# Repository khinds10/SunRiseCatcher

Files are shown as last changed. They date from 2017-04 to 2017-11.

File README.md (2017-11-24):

# Daily SunRise Catcher
#### Takes many pictures for you at sunrise, capturing the most colorful.

**Bedside Display**
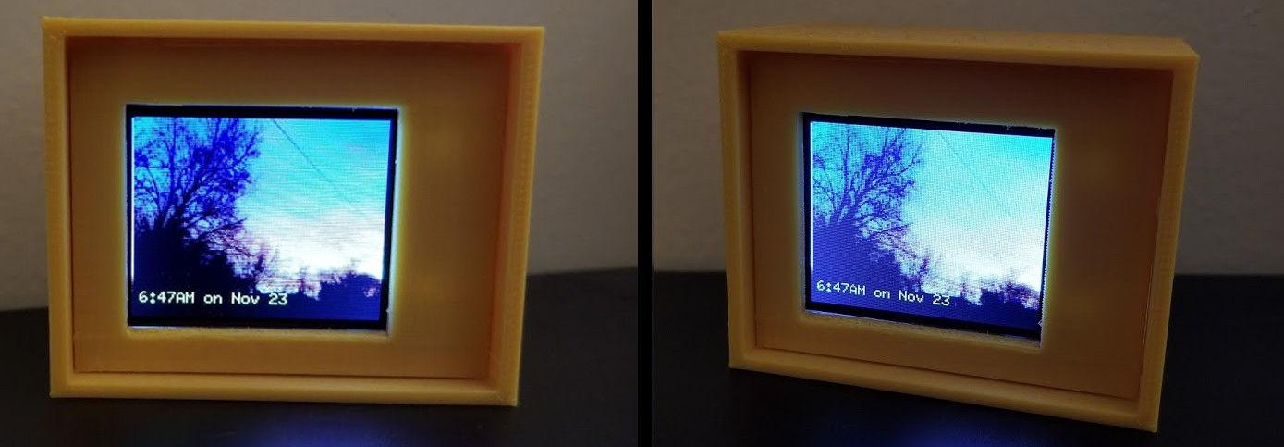
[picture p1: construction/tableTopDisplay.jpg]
Table Top Display


**Morning Email**
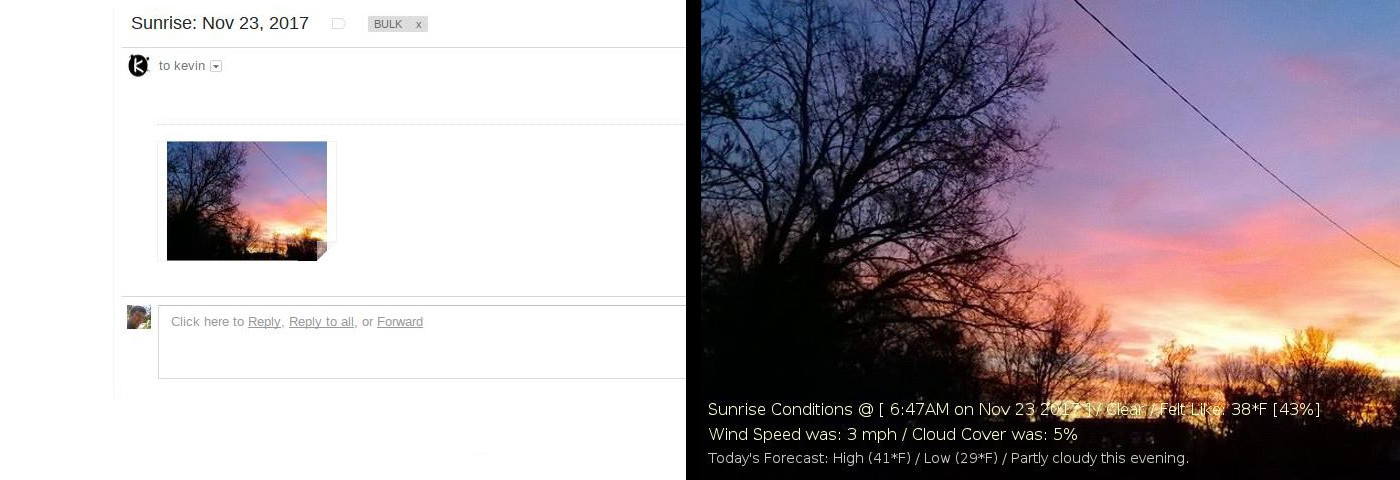
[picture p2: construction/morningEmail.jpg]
Morning Email


#### Flashing RaspberriPi Hard Disk / Install Required Software (Using Ubuntu Linux)

Download "RASPBIAN JESSIE LITE"
https://www.raspberrypi.org/downloads/raspbian/

**Create your new hard disk for DashboardPI**
>Insert the microSD to your computer via USB adapter and create the disk image using the `dd` command
>
> Locate your inserted microSD card via the `df -h` command, unmount it and create the disk image with the disk copy `dd` command
> 
> $ `df -h`
> */dev/sdb1       7.4G   32K  7.4G   1% /media/XXX/1234-5678*
> 
> $ `umount /dev/sdb1`
> 
> **Caution: be sure the command is completely accurate, you can damage other disks with this command**
> 
> *if=location of RASPBIAN JESSIE LITE image file*
> *of=location of your microSD card*
> 
> $ `sudo dd bs=4M if=/path/to/raspbian-jessie-lite.img of=/dev/sdb`
> *(note: in this case, it's /dev/sdb, /dev/sdb1 was an existing factory partition on the microSD)*

**Setting up your RaspberriPi**

*Insert your new microSD card to the raspberrypi and power it on with a monitor connected to the HDMI port*

Login
> user: **pi**
> pass: **raspberry**

Change your account password for security
>`sudo passwd pi`

Enable RaspberriPi Advanced Options
>`sudo raspi-config`

Choose:
`1 Expand File System`

`6 Enable Camera`

`9 Advanced Options`
>`A2 Hostname`
>*change it to "SunRise"*
>
>`A4 SSH`
>*Enable SSH Server*
>
>`A7 I2C`
>*Enable i2c interface*

**Enable the English/US Keyboard**

>`sudo nano /etc/default/keyboard`

> Change the following line:
>`XKBLAYOUT="us"`

**Reboot PI for Keyboard layout changes / file system resizing to take effect**
>$ `sudo shutdown -r now`

**Auto-Connect to your WiFi**

>`sudo nano /etc/wpa_supplicant/wpa_supplicant.conf`

Add the following lines to have your raspberrypi automatically connect to your home WiFi
*(if your wireless network is named "linksys" for example, in the following example)*

	network={
	   ssid="linksys"
	   psk="WIRELESS PASSWORD HERE"
	}

**Reboot PI to connect to WiFi network**

>$ `sudo shutdown -r now`
>
>Now that your PI is finally on the local network, you can login remotely to it via SSH.
>But first you need to get the IP address it currently has.
>
>$ `ifconfig`
>*Look for "inet addr: 192.168.XXX.XXX" in the following command's output for your PI's IP Address*

**Go to another machine and login to your raspberrypi via ssh**

> $ `ssh pi@192.168.XXX.XXX`

**Start Installing required packages**

>$ `sudo apt-get update`
>
>$ `sudo apt-get upgrade`
>
>$ `sudo apt-get install vim git python-smbus i2c-tools python-imaging python-smbus build-essential python-dev rpi.gpio python3 python3-pip libi2c-dev python-picamera python-opencv`

**Update local timezone settings**

>$ `sudo dpkg-reconfigure tzdata`

> select your timezone using the interface

**Setup the simple directory `l` command [optional]**

>$ `vi ~/.bashrc`
>
>*add the following line:*
>
>$ `alias l='ls -lh'`
>
>$ `source ~/.bashrc`

**Fix VIM default syntax highlighting [optional]**

>$ `sudo vi /etc/vim/vimrc`
>
>uncomment the following line:
>
>_syntax on_

**Clone SunRise repository**

`$ cd ~`

`$ https://github.com/khinds10/SunRiseCatcher.git`

**Install the SSMTP mail program to gmail your sunrise pictures**

>$ `sudo apt-get update && apt-get install ssmtp`

>$ `sudo apt-get install sharutils`

**Edit the SSMTP config**

>$ `sudo vi /etc/ssmtp/ssmtp.conf`

>comment out: `mailhub=mail`
>comment out: `FromLineOverride=YES`

>Add the following lines to the end of the file
>
>`AuthUser=your-gmail-address@gmail.com`
>`AuthPass=YOUR GMAIL PASSWORD`
>`FromLineOverride=YES`
>`mailhub=smtp.gmail.com:587`
>`UseSTARTTLS=YES`

**Test emailing to yourself using the installed command**
>$ `echo "This is a test" | mail -s "Test" your-gmail-address@gmail.com`

## Supplies Needed

**Digole 1.8" Serial:UART/I2C/SPI True Color TFT LCD 160x128 Display Module for Arduino/PIC/AVR/PI**
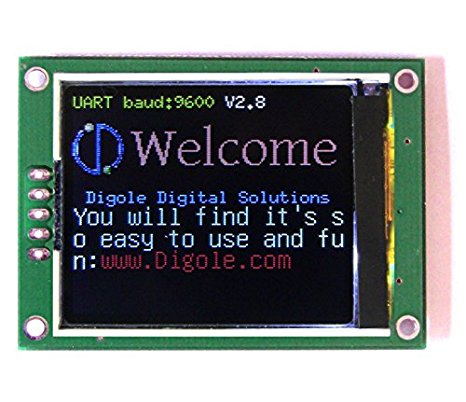
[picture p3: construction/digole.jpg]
Digole Display


**RaspberriPi Zero (W Model w/ built in wireless)**
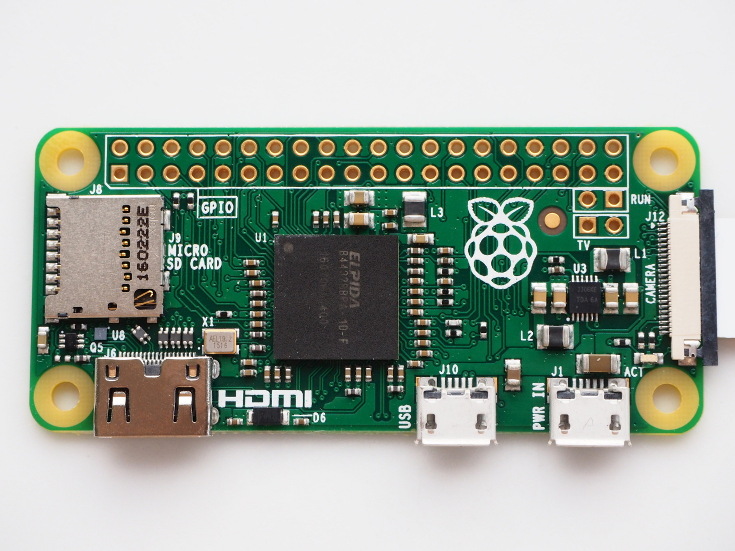
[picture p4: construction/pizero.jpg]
PiZero W


## Build and wire the device

**Prepare the Digole Display for i2C**

On the back of the Digole Display, solder the jumper to assign the display to use the i2c protocol 

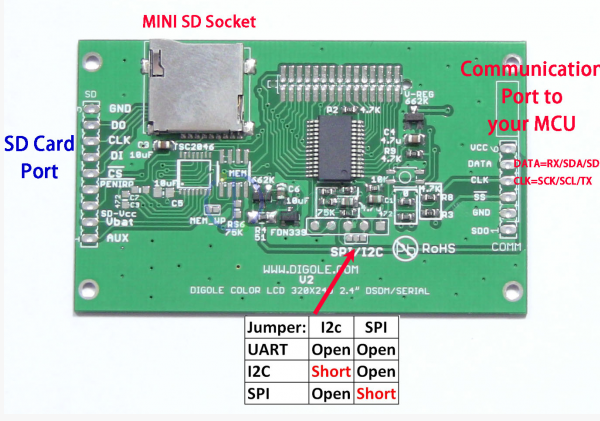
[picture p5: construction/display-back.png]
Digole Display Back


**Digole Display**

Connect the display to the RPi as follows using the below diagram

> GND -> GND
>
> DATA -> SDA
>
> CLK -> SCL
>
> VCC -> 3V

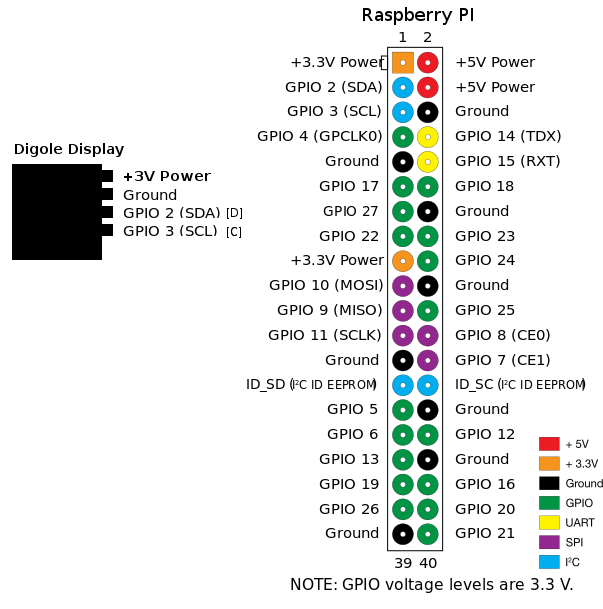
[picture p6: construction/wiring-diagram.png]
Digole Wiring Digole Wiring


## Print the Project Enclosure

Using a 3D printer print the enclosure files included in the 'enclosure/' folder. .x3g files are MakerBot compatible. You can also use the .stl and .blend (Blender Program) files to edit and create your own improvements to the design.

## Assembly

Put the camera and the pizero in the case, attach the front panel to cover any marks from the printing process

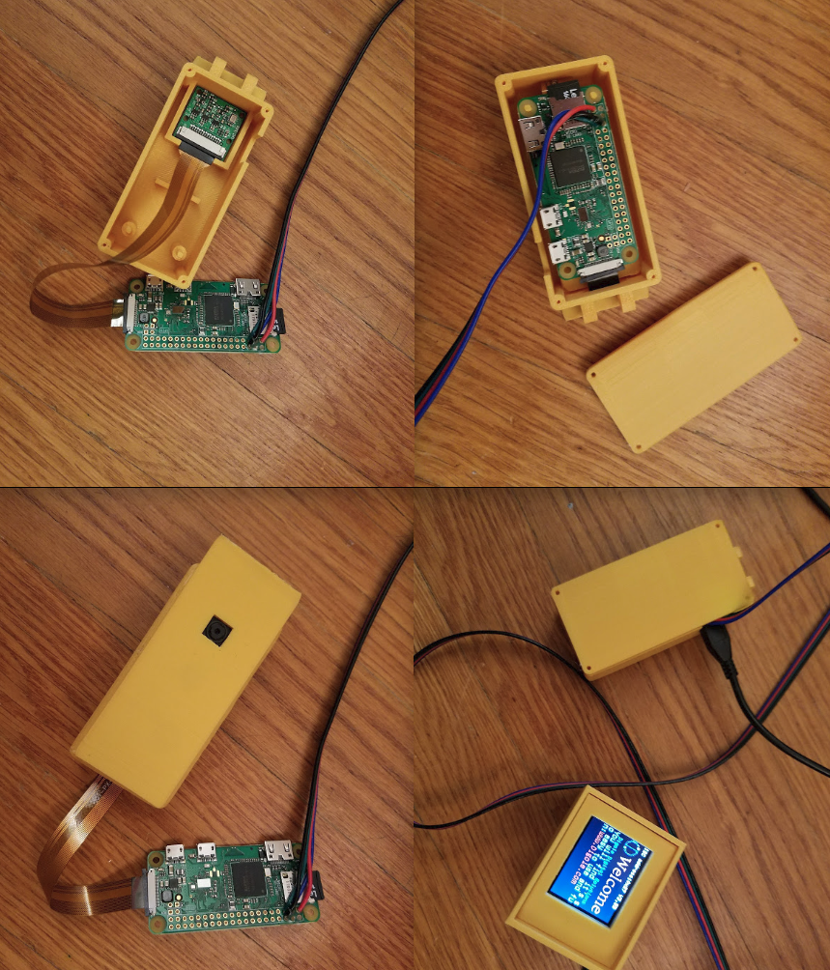
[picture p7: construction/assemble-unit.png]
Assemble Unit


Glue the display to the front panel of the display box and put the wiring through the back hole

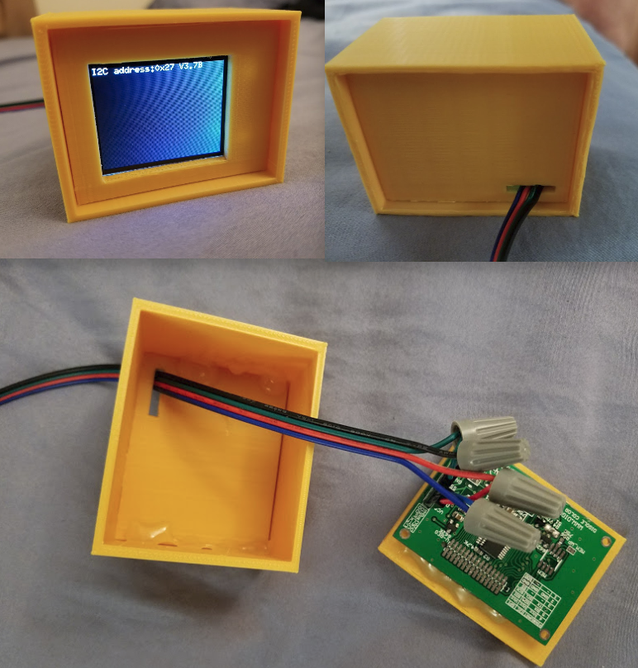
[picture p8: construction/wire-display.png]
Mount Display


Mount the display in an eastern facing window

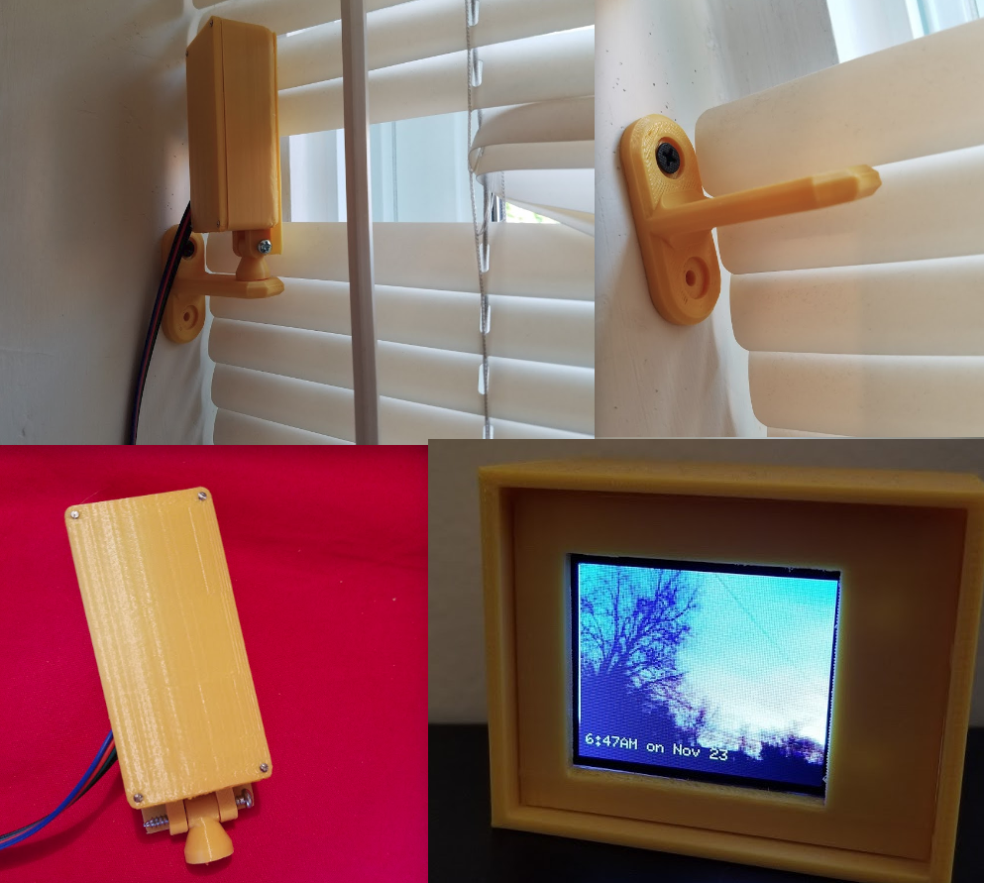
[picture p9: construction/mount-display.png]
Mount Display


**Change your settings.py to match your personal preferences**

`settings.py`

> emailAddress = 'your-email@gmail.com'
>
> weatherAPIURL = 'https://api.forecast.io/forecast/'
> weatherAPIKey = 'YOUR FORECAST.IO KEY HERE'
>
> numberOfSunriseCaptures = 15
> timeToCaptureMinutes = 30

> latitude = 42.4152778
> longitude = -71.1569444

**Run Daily at 4am (via crontab)**

Add the following line to your PI crontab to run the capture program starting at 4am

>$ `crontab -e`
>`0  4  *  *  *  python /home/pi/SunRiseCatcher/capture.py > /home/pi/SunRiseCatcher/capture.out`

### FINISHED!

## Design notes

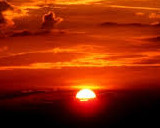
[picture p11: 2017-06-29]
display/image.jpg

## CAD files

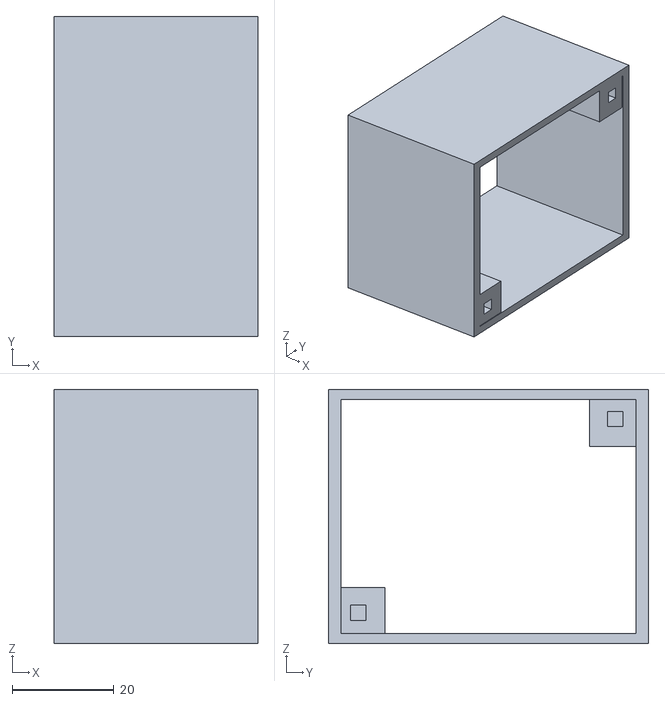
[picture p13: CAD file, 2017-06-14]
enclosure/DisplayBox-Main.stl
40.0 x 62.9 x 49.9

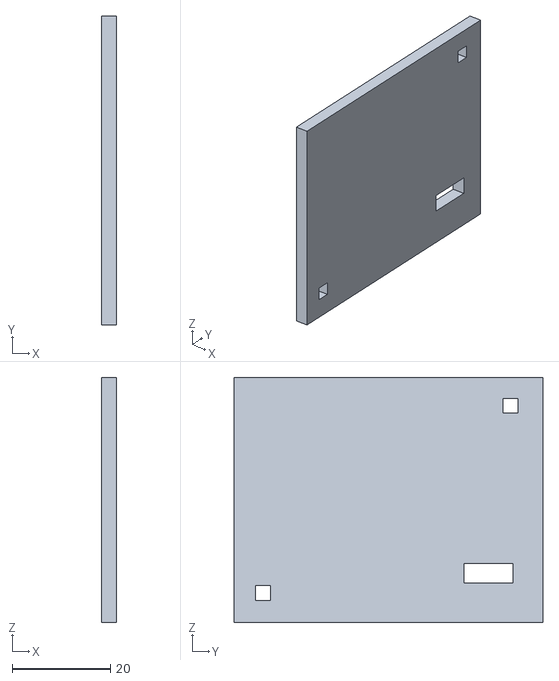
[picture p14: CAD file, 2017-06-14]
enclosure/DisplayBox-Back.stl
3.00 x 62.9 x 49.9

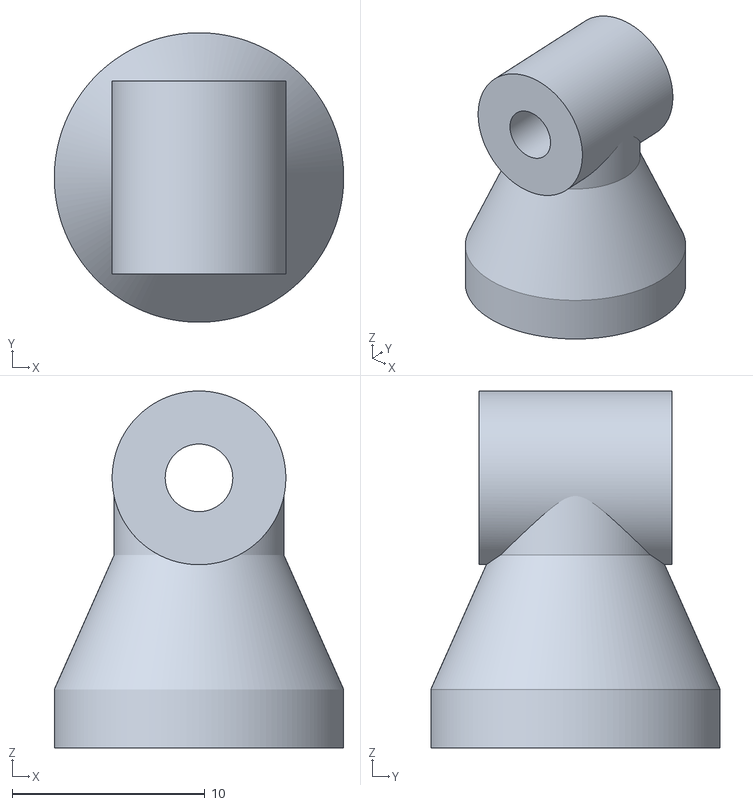
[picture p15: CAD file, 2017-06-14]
enclosure/PigeonSwivel.stl
15.0 x 15.0 x 18.5

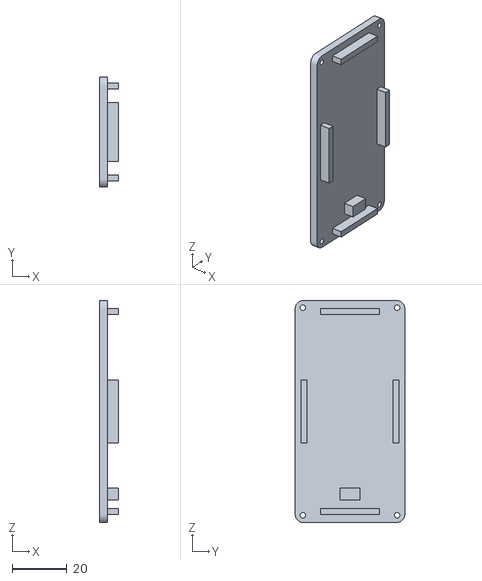
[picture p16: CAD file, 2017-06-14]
enclosure/PigeonLid.stl
7.00 x 40.0 x 81.0

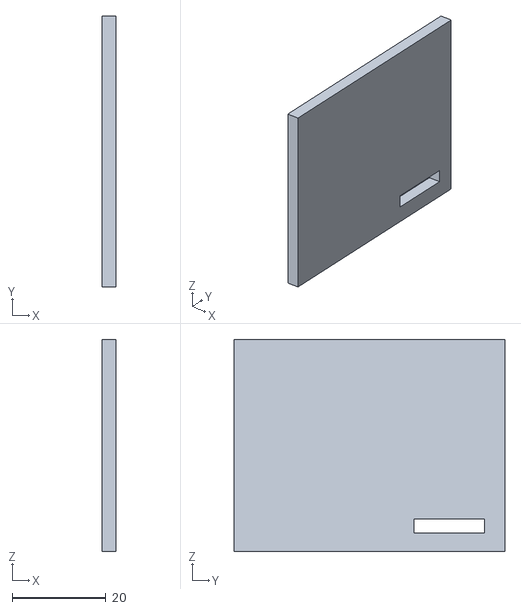
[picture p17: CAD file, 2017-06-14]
enclosure/DisplayBack.stl
3.00 x 57.7 x 45.2

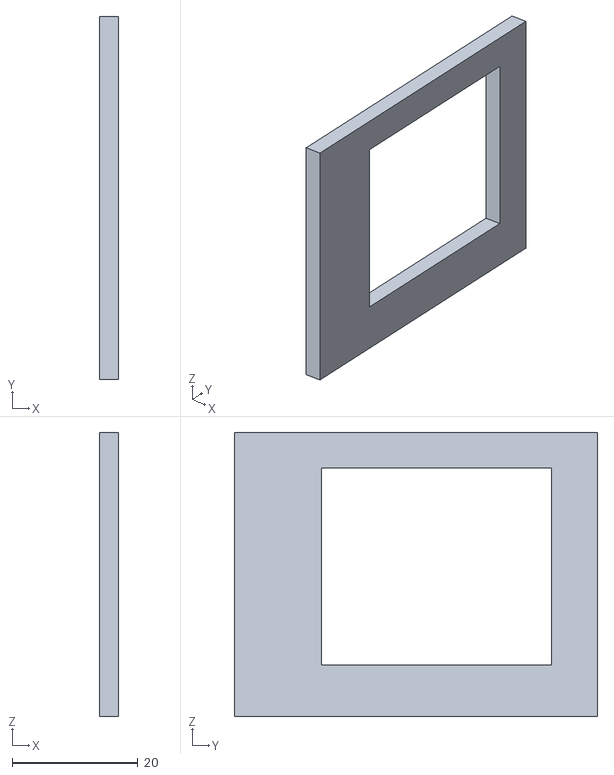
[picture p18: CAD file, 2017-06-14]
enclosure/DisplayBox-Front.stl
3.00 x 57.7 x 45.2

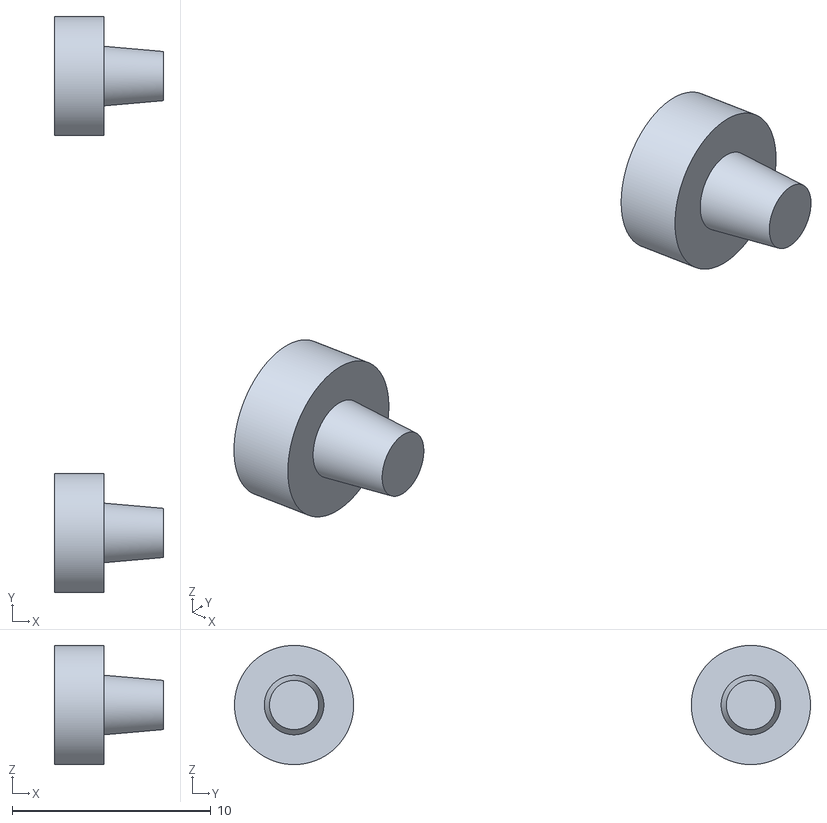
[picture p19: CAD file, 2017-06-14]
enclosure/PigeonBoardPins.stl
5.50 x 29.0 x 6.00

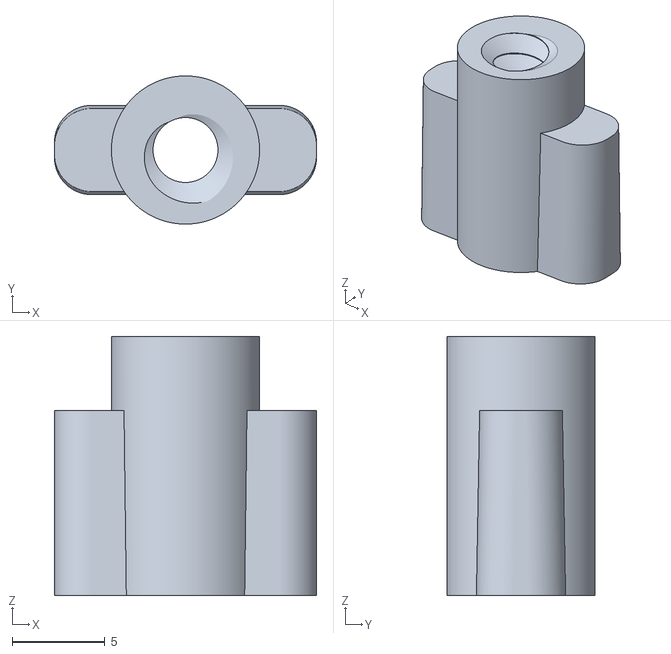
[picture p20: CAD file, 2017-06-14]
enclosure/PigeonWingnut.stl
14.1 x 8.00 x 14.0

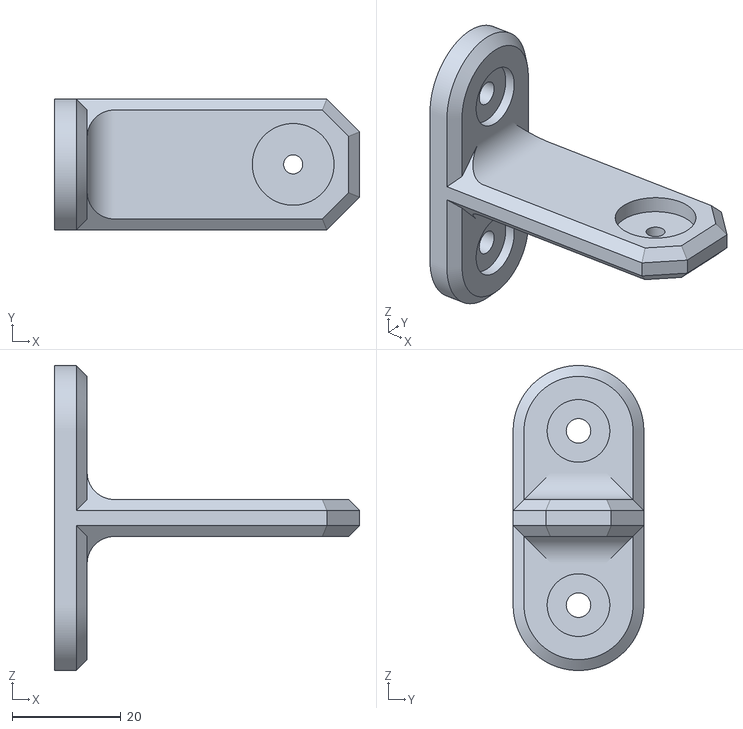
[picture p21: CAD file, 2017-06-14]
enclosure/PigeonMount.stl
56.0 x 24.0 x 56.0

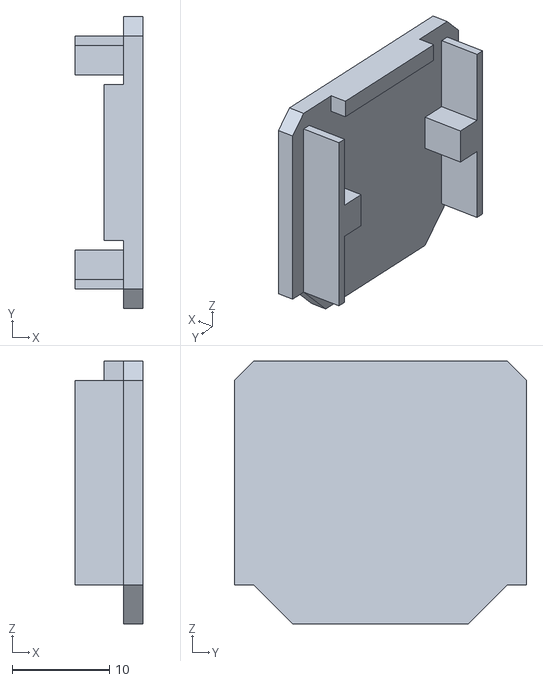
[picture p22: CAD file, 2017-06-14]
enclosure/PigeonHousingCover.stl
7.00 x 30.0 x 27.0

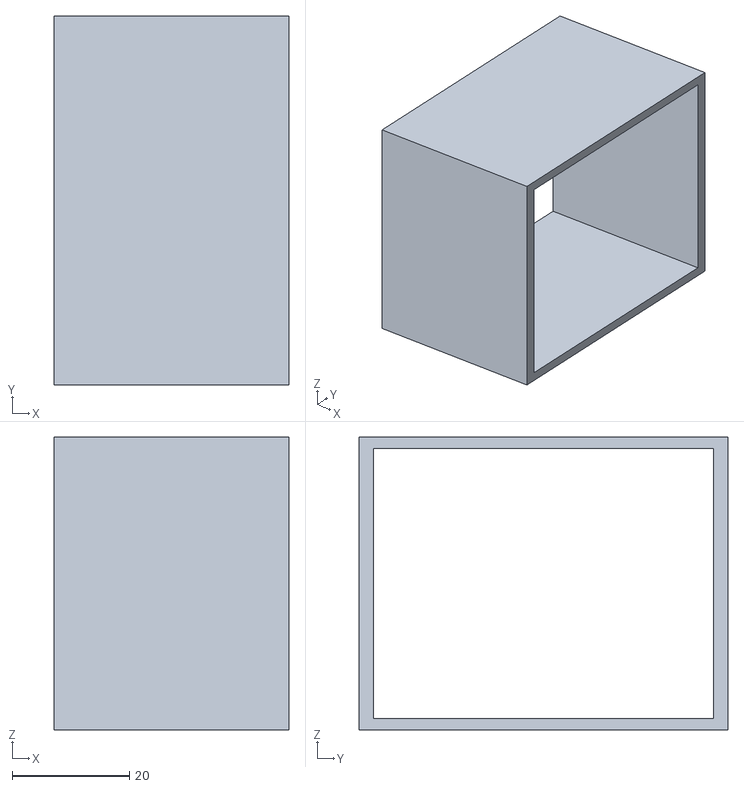
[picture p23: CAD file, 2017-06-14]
enclosure/DisplayBox.stl
40.0 x 62.9 x 49.9

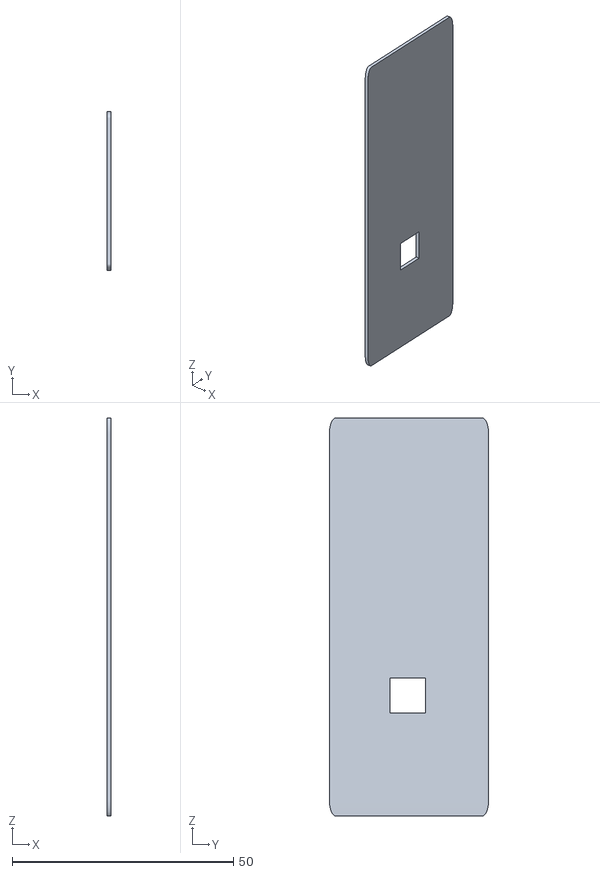
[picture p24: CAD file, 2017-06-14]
enclosure/PigeonFrontCover.stl
1.00 x 36.0 x 90.0

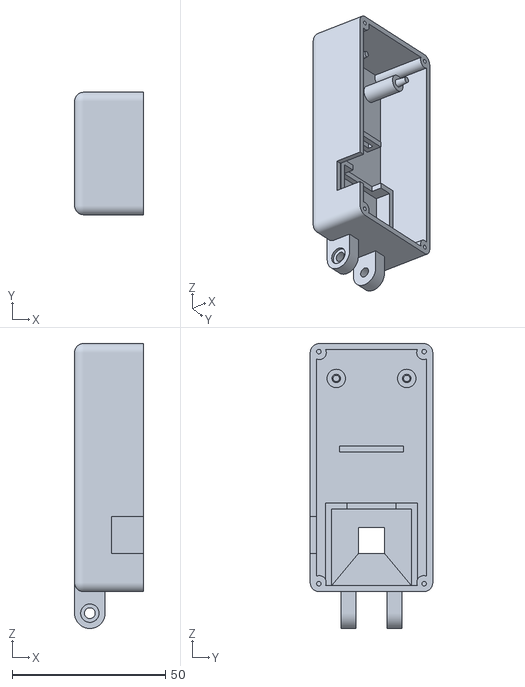
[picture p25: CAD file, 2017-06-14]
enclosure/PigeonHousing.stl
22.5 x 40.0 x 93.0

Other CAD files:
enclosure/SunRiseCatcher.blend
enclosure/SunRiseHousing.blend

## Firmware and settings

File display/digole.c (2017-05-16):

/////////////////////////////////
// Digole Digital
/////////////////////////////////
#include <arpa/inet.h>
#include <dirent.h>
#include <errno.h>
#include <net/if.h>
#include <netinet/in.h>
#include <netinet/in.h>
#include <pthread.h>
#include <stdint.h>
#include <stdio.h>
#include <stdlib.h>
#include <string.h>
#include <stropts.h>
#include <sys/ioctl.h>
#include <sys/socket.h>
#include <sys/types.h>
#include <sys/time.h>
#include <time.h>
#include <unistd.h>
#include <inttypes.h>
#include <linux/i2c-dev.h>
#include <fcntl.h>
#include <sys/ioctl.h>
#include <sys/stat.h>
#include "imageData.h"

#define _TEXT_ 0
#define _GRAPH_ 1
#define _rs 0
#define _rst 2
#define LCDWIDTH 128
#define LCDHEIGHT 64

// an abs() :)
#define abs(a) (((a) < 0) ? -(a) : (a))

// bit set
#define _BV(bit) (0x1 << (bit))
#define swap(a, b) { uint8_t t = a; a = b; b = t; }

int fd,fd2;
const unsigned char fonts[] = {6, 10, 18, 51, 120, 123};

// name of the port we will be using, Rasberry Pi model B (i2c-1)
char *fileName = "/dev/i2c-1";

// address of I2C device Digole
int  address = 0x27;

void delay (unsigned int howLong){
  struct timespec sleeper, dummy ;
  sleeper.tv_sec  = (time_t)(howLong / 1000) ;
  sleeper.tv_nsec = (long)(howLong % 1000) * 1000000 ;
  nanosleep (&sleeper, &dummy) ;
}
 int writebyte (uint8_t command) {
	    if( i2c_smbus_write_byte( fd, command ) < 0 ) {
            printf("\nError writing to i2c slave ");
			return -1;
        }
		return 0;
 }
 int writecmd(char *command) {
		char tmp[1000];
		int i;
		sprintf(tmp,"%s",command);
        printf("\nDigole CMD: %s ",command);
		for (i=0;i<strlen(tmp);i++) {
			printf("\nCharacter is: %c",tmp[i]);
		    if ((writebyte(tmp[i]))==-1) {
				printf("\nError writing to i2c slave ");
				return -1;
			}
		}
		return 0;
 }
void setRot90(void) {
    writecmd("SD1");
}
void setRot180(void) {
    writecmd("SD2");
}
void setRot270(void) {
    writecmd("SD3");
}
void undoRotation(void) {
    writecmd("SD0");
}
void setRotation(uint8_t d) {
    writecmd("SD");
    writebyte(d);
}
void setContrast(uint8_t c) {
    writecmd("CT");
    writebyte(c);
}
int print(char *command) {
    char tmp[1000];
    writecmd("TT");
    writecmd(command);
    writebyte(0);
    return 0;
}
void displayStartScreen(uint8_t c) {
    writecmd("DSS");
    writebyte(c);
}
void drawBox(uint8_t x, uint8_t y, uint8_t w, uint8_t h) {
    writecmd("FR");
    writebyte(x);
    writebyte(y);
    writebyte(x + w);
    writebyte(y + h);
}
void drawFrame(uint8_t x, uint8_t y, uint8_t w, uint8_t h) {
    writecmd("DR");
    writebyte(x);
    writebyte(y);
    writebyte(x + w);
    writebyte(y + h);
}

void setRBGColor(uint8_t r, uint8_t g, uint8_t b){
    writecmd("ESC");
    writebyte(r);
    writebyte(g);
    writebyte(b);
}

void setColor(uint8_t color) {
    writecmd("SC");
    writebyte(color);
}
void drawBoxfill(uint8_t x, uint8_t y, uint8_t w, uint8_t h) {
	drawBox(x, y, w,h);
	drawFrame(x, y, w,h);
}
void clearobd() {
	setColor(0);
	drawBox(0, 0, 128,57);
	setColor(1);
}
void drawCircle(uint8_t x, uint8_t y, uint8_t r, uint8_t f) {
    writecmd("CC");
    writebyte(x);
    writebyte(y);
    writebyte(r);
    writebyte(f);
}
void drawDisc(uint8_t x, uint8_t y, uint8_t r) {
    drawCircle(x, y, r, 1);
}
void drawPixel(uint8_t x, uint8_t y, uint8_t color) {
    writecmd("DP");
    writebyte(x);
    writebyte(y);
    writebyte(color);
}
void drawLine(uint8_t x, uint8_t y, uint8_t x1, uint8_t y1) {
    writecmd("LN");
    writebyte(x);
    writebyte(y);
    writebyte(x1);
    writebyte(y1);
}
void drawLineTo(uint8_t x, uint8_t y) {
    writecmd("LT");
    writebyte(x);
    writebyte(y);
}
void drawHLine(uint8_t x, uint8_t y, uint8_t w) {
    drawLine(x, y, x + w, y);
}
void drawVLine(uint8_t x, uint8_t y, uint8_t h) {
    drawLine(x, y, x, y + h);
}
void nextTextLine(void) {
    writebyte((uint8_t) 0);
    writecmd("TRT");
}
void setFont(uint8_t font) {
    writecmd("SF");
    writebyte(font);
}
void directCommand(uint8_t d) {
    writecmd("MCD");
    writebyte(d);
}
void directData(uint8_t d) {
    writecmd("MDT");
    writebyte(d);
}
void moveArea(uint8_t x0, uint8_t y0, uint8_t x1, uint8_t y1, char xoffset, char yoffset) {
    writecmd("MA");
    writebyte(x0);
    writebyte(y0);
    writebyte(x1);
    writebyte(y1);
    writebyte(xoffset);
    writebyte(yoffset);
}
void uploadStartScreen(int lon,  uint8_t *data,int xdelay) {
     int j,y;
     uint8_t c;
    writecmd("SSS");
    writebyte((uint8_t) (lon % 256));
    writebyte((uint8_t) (lon / 256));
    for (j = 0; j < lon;j++) {
        delay(xdelay);
        c=*(data+j);
        writebyte(c);
		printf(" 0x%.2X ",c);
		if ((j%16)==0) printf(" ");
    }
}
void uploadUserFont(int lon, uint8_t *data, uint8_t sect) {
     uint8_t c;
	 int j;
    writecmd("SUF");
    writebyte(sect);
    writebyte((uint8_t) (lon % 256));
    writebyte((uint8_t) (lon / 256));
    for ( j = 0; j < lon; j++) {
        if((j%32)==0) delay(10);
        delay(2);
        c=*(data+j);
        writebyte(c);
    }
}
void clearScreen(void) {
        writebyte('C');
		writebyte('L');
		writebyte(0);
		writebyte('C');
		writebyte('L');
		writebyte(0);
}
//set display mode
void setMode(uint8_t m) {
        writecmd("DM");
        writebyte(m);
}
//set text position back to previous, only one back allowed
void setTextPosBack(void) {
	writecmd("ETB");
}
void setTextPosOffset(char xoffset, char yoffset) {
	writecmd("ETO");
	writebyte(xoffset);
	writebyte(yoffset);
}
void setTextPosAbs(uint8_t x, uint8_t y) {
	writecmd("ETP");
	writebyte(x);
	writebyte(y);
}
void setLinePattern(uint8_t pattern) {
	writecmd("SLP");
	writebyte(pattern);
 }
void setPrintPos(uint8_t x, uint8_t y, uint8_t graph ) {
        if (graph == _TEXT_)
            writecmd("TP");
		else
            writecmd("GP");
         writebyte(x);
         writebyte(y);
}
void disableCursor(void) {
    writecmd("CS0");
}
void enableCursor(void) {
    writecmd("CS1");
}
void drawStr(uint8_t x, uint8_t y, char *s) {
		setTextPosOffset(x,y);
		print(s);
}
/*----------Functions for Graphic LCD/OLED adapters only---------*/
void drawBitmap(uint8_t x, uint8_t y, uint8_t w, uint8_t h, const uint8_t *bitmap) {
    uint8_t i = 0;
	int j;
    if ((w & 7) != 0)
        i = 1;
    writecmd("DIM");
    writebyte(x); //x;
    writebyte(y);
    writebyte(w);
    writebyte(h);
    for ( j = 0; j < h * ((w >> 3) + i); j++) {
        writebyte(*(bitmap + j));
    }
}

// write 3 colors bytes for pixel image to the display
void drawBitmap256K(uint8_t x, uint8_t y, uint8_t w, uint8_t h, const uint8_t *bitmap,uint8_t c ) {
	int j;
    writecmd("EDIM3");
    writebyte(x);
    writebyte(y);
    writebyte(w);
    writebyte(h);
    for ( j = 0; j < (h * w * 3); j++) {
        writebyte(*(bitmap + j));
    }
}

void drawBitmap256(uint8_t x, uint8_t y, uint8_t w, uint8_t h, const uint8_t *bitmap,uint8_t c ) {
	int j;
    writecmd("EDIM1");
    writebyte(x);
    writebyte(y);
    writebyte(w);
    writebyte(h);
    for ( j = 0; j < h * w; j++) {
        writebyte(*(bitmap + j));
    }
}
void drawBitmapc(uint8_t x, uint8_t y, uint8_t w, uint8_t h, const uint8_t *bitmap,uint8_t c ) {
    uint8_t i = 0;
	int j;
	if (c!=0) c=0xff;
    if ((w & 7) != 0)
        i = 1;
    writecmd("DIM");
    writebyte(x);
    writebyte(y);
    writebyte(w);
    writebyte(h);
    for ( j = 0; j < h * ((w >> 3) + i); j++) {
        writebyte((*(bitmap + j))^c);
    }
}
const char *byte_to_binary(int x) {
    static char b[9];
    b[0] = '\0';
    int z;
    for (z = 128; z > 0; z >>= 1){
        strcat(b, ((x & z) == z) ? "1" : "0");
    }
    return b;
}
 int printxy(uint8_t x, uint8_t y, char *command) {
	setPrintPos(x, y,_TEXT_);
	writecmd("TT");
	writecmd(command);
	writebyte(0);
	return 0;
 }
 int printxy_abs(uint8_t x, uint8_t y, char *command) {
	setTextPosAbs(x, y);
	writecmd("TT");
	writecmd(command);
	writebyte(0);
	return 0;
 }
 int printxyf_abs(uint8_t x, uint8_t y,uint8_t font, char *command) {
	setFont(fonts[font]);
	setTextPosAbs(x, y);
	writecmd("TT");
	writecmd(command);
	writebyte(0);
	return 0;
 }
int printxyf(uint8_t x, uint8_t y,uint8_t font, char *command) {
	setFont(fonts[font]);
	setPrintPos(x, y,_TEXT_);
	writecmd("TT");
	writecmd(command);
	writebyte(0);
	return 0;
 }
int printnxyf(uint8_t x, uint8_t y,uint8_t font, int command) {
    char tmp[100];
    sprintf(tmp,"%d",command);
    setFont(fonts[font]);
    setPrintPos(x, y,_TEXT_);
    writecmd("TT");
    writecmd(tmp);
    writebyte(0);
    return 0;
 }
 int printnxyf_abs(uint8_t x, uint8_t y,uint8_t font, int command) {
    char tmp[100];
    sprintf(tmp,"%d",command);
    setFont(fonts[font]);
    setTextPosAbs(x, y);
    writecmd("TT");
    writecmd(tmp);
    writebyte(0);
    return 0;
 }
int LCDInit( uint8_t contrast) {
    // Open port for reading and writing
    if ((fd = open (fileName, O_RDWR)) < 0) {
        printf(" Failed to open i2c port ");
        return -1;
    }
    // Set the port options and set the address of the device
    if (ioctl(fd, I2C_SLAVE, address) < 0) {
        printf(" Unable to get bus access to talk to slave ");
        return -1;
    }
	return (0);
}
void LCDdrawbitmap(uint8_t x, uint8_t y, uint8_t *bitmap, uint8_t w, uint8_t h,uint8_t color,uint8_t *dest) {
uint8_t j,i,jj;
uint8_t o,p,k;
printf(" 000 0b ");
k=0;
for (p=0;p<(w/8);p++)
  for (o=0;o<=7;o++) {
		for ( j=0; j<h; j++) {
			for ( i=0; i<(w/8); i++ ) {
				uint8_t d = *(bitmap + i + (j)*w/8);
				for (jj = 8; jj>0; jj--)	{
					if (((jj-1)==(7-o)) && (i==p)) {
						if (d & _BV(jj-1))
						  printf("1");
						else
						  printf("0");
						k++;
						if (k%8==0)
							printf(",0b");
					 }
				}
			}
		}
		k=0;
		printf(" %.03d 0b ",(p*8)+o);
	}
}

int main (int argc, char* argv[]) {
    int i=0;
	LCDInit(0);
    
    // show incoming commands
    printf(" %s ", argv[0]);
    printf(" arg%d=%s ", 1, argv[1]);
    printf(" arg%d=%s ", 2, argv[2]);

    // parse command to char
    char digoleCommand[100];
    sprintf(digoleCommand,"%s",argv[1]);
    
    // based on command issue call to Digole screen
    if (strcmp(digoleCommand, "setRot90") == 0) {
        setRot90();
    } else if (strcmp(digoleCommand, "setRot180") == 0) {
        setRot180();
    } else if (strcmp(digoleCommand, "setRot270") == 0) {
        setRot270();
    } else if (strcmp(digoleCommand, "undoRotation") == 0) {
        undoRotation();
    } else if (strcmp(digoleCommand, "setRotation") == 0) {
        setRotation((uint8_t)atoi(argv[2]));
    } else if (strcmp(digoleCommand, "setContrast") == 0) {
        setContrast((uint8_t)atoi(argv[2]));
    } else if (strcmp(digoleCommand, "displayStartScreen") == 0) {
        displayStartScreen((uint8_t)atoi(argv[2]));
    } else if (strcmp(digoleCommand, "drawBox") == 0) {
        drawBox((uint8_t)atoi(argv[2]), (uint8_t)atoi(argv[3]), (uint8_t)atoi(argv[4]), (uint8_t)atoi(argv[5]));
    } else if (strcmp(digoleCommand, "drawFrame") == 0) {
        drawFrame((uint8_t)atoi(argv[2]), (uint8_t)atoi(argv[3]), (uint8_t)atoi(argv[4]), (uint8_t)atoi(argv[5]));
    } else if (strcmp(digoleCommand, "setColor") == 0) {
        setColor((uint8_t)atoi(argv[2]));
    } else if (strcmp(digoleCommand, "drawBoxfill") == 0) {
        drawBoxfill((uint8_t)atoi(argv[2]), (uint8_t)atoi(argv[3]), (uint8_t)atoi(argv[4]), (uint8_t)atoi(argv[5]));
    } else if (strcmp(digoleCommand, "clearobd") == 0) {
        clearobd();
    } else if (strcmp(digoleCommand, "drawCircle") == 0) {
        drawCircle((uint8_t)atoi(argv[2]), (uint8_t)atoi(argv[3]), (uint8_t)atoi(argv[4]), (uint8_t)atoi(argv[5]));
    } else if (strcmp(digoleCommand, "drawDisc") == 0) {
        drawDisc((uint8_t)atoi(argv[2]), (uint8_t)atoi(argv[3]), (uint8_t)atoi(argv[4]));
    } else if (strcmp(digoleCommand, "drawPixel") == 0) {
        drawPixel((uint8_t)atoi(argv[2]), (uint8_t)atoi(argv[3]), (uint8_t)atoi(argv[4]));
    } else if (strcmp(digoleCommand, "drawLine") == 0) {
        drawLine((uint8_t)atoi(argv[2]), (uint8_t)atoi(argv[3]), (uint8_t)atoi(argv[4]), (uint8_t)atoi(argv[5]));
    } else if (strcmp(digoleCommand, "drawLineTo") == 0) {
        drawLineTo((uint8_t)atoi(argv[2]), (uint8_t)atoi(argv[3]));
    } else if (strcmp(digoleCommand, "drawHLine") == 0) {
        drawHLine((uint8_t)atoi(argv[2]), (uint8_t)atoi(argv[3]), (uint8_t)atoi(argv[4]));
    } else if (strcmp(digoleCommand, "drawVLine") == 0) {
        drawVLine((uint8_t)atoi(argv[2]), (uint8_t)atoi(argv[3]), (uint8_t)atoi(argv[4]));
    } else if (strcmp(digoleCommand, "nextTextLine") == 0) {
        nextTextLine();
    } else if (strcmp(digoleCommand, "setFont") == 0) {
        setFont((uint8_t)atoi(argv[2]));
    } else if (strcmp(digoleCommand, "directCommand") == 0) {
        directCommand((uint8_t)atoi(argv[2]));
    } else if (strcmp(digoleCommand, "directData") == 0) {
        directData((uint8_t)atoi(argv[2]));
    } else if (strcmp(digoleCommand, "moveArea") == 0) {
        moveArea((uint8_t)atoi(argv[2]), (uint8_t)atoi(argv[3]), (uint8_t)atoi(argv[4]), (uint8_t)atoi(argv[5]), (uint8_t)atoi(argv[6]), (uint8_t)atoi(argv[7]));
    } else if (strcmp(digoleCommand, "uploadStartScreen") == 0) {
        //uploadStartScreen(int lon,  uint8_t *data,int xdelay);
    } else if (strcmp(digoleCommand, "uploadUserFont") == 0) {
        //uploadUserFont(int lon, uint8_t *data, uint8_t sect);
    } else if (strcmp(digoleCommand, "clear") == 0) {
        clearScreen();
    } else if (strcmp(digoleCommand, "setMode") == 0) {
        setMode((uint8_t)atoi(argv[2]));
    } else if (strcmp(digoleCommand, "setTextPosBack") == 0) {
        setTextPosBack();
    } else if (strcmp(digoleCommand, "setTextPosOffset") == 0) {
        setTextPosOffset((uint8_t)atoi(argv[2]), (uint8_t)atoi(argv[3]));
    } else if (strcmp(digoleCommand, "setTextPosAbs") == 0) {
        setTextPosAbs((uint8_t)atoi(argv[2]), (uint8_t)atoi(argv[3]));
    } else if (strcmp(digoleCommand, "setLinePattern") == 0) {
        setLinePattern((uint8_t)atoi(argv[2]));
    } else if (strcmp(digoleCommand, "setPrintPos") == 0) {
        setPrintPos((uint8_t)atoi(argv[2]), (uint8_t)atoi(argv[3]), (uint8_t)atoi(argv[4]));
    } else if (strcmp(digoleCommand, "disableCursor") == 0) {
        disableCursor();
    } else if (strcmp(digoleCommand, "enableCursor") == 0) {
        enableCursor();
    } else if (strcmp(digoleCommand, "drawStr") == 0) {
        drawStr((uint8_t)atoi(argv[2]), (uint8_t)atoi(argv[3]), argv[4]);
    } else if (strcmp(digoleCommand, "drawBitmap") == 0) {
        //drawBitmap((uint8_t)atoi(argv[2]), (uint8_t)atoi(argv[3]), (uint8_t)atoi(argv[4]), (uint8_t)atoi(argv[5]), (uint8_t)atoi(argv[2]));
    } else if (strcmp(digoleCommand, "drawBitmapc") == 0) {
        //drawBitmapc((uint8_t)atoi(argv[2]), (uint8_t)atoi(argv[2]), (uint8_t)atoi(argv[2]), (uint8_t)atoi(argv[2]), const uint8_t *bitmap,uint8_t c );
    } else if (strcmp(digoleCommand, "print") == 0) {
        print(argv[2]);
    } else if (strcmp(digoleCommand, "printxy") == 0) {
        printxy((uint8_t)atoi(argv[2]), (uint8_t)atoi(argv[3]), argv[4]);
    } else if (strcmp(digoleCommand, "printxy_abs") == 0) {
        printxy_abs((uint8_t)atoi(argv[2]), (uint8_t)atoi(argv[3]), argv[4]);
    } else if (strcmp(digoleCommand, "printxyf_abs") == 0) {
        printxyf_abs((uint8_t)atoi(argv[2]), (uint8_t)atoi(argv[3]),(uint8_t)atoi(argv[4]), argv[5]) ;
    } else if (strcmp(digoleCommand, "printxyf") == 0) {
        printxyf((uint8_t)atoi(argv[2]), (uint8_t)atoi(argv[3]),(uint8_t)atoi(argv[4]), argv[5]);
    } else if (strcmp(digoleCommand, "printnxyf") == 0) {
        printnxyf((uint8_t)atoi(argv[2]), (uint8_t)atoi(argv[3]),(uint8_t)atoi(argv[4]), (uint8_t)atoi(argv[5]));
    } else if (strcmp(digoleCommand, "printnxyf_abs") == 0) {
        printnxyf_abs((uint8_t)atoi(argv[2]), (uint8_t)atoi(argv[3]),(uint8_t)atoi(argv[4]), (uint8_t)atoi(argv[5]));
    } else if (strcmp(digoleCommand, "LCDdrawbitmap") == 0) {
        //LCDdrawbitmap((uint8_t)atoi(argv[2]), (uint8_t)atoi(argv[3]), (uint8_t)atoi(argv[4]), (uint8_t)atoi(argv[5]), (uint8_t)atoi(argv[6]),(uint8_t)atoi(argv[7]),(uint8_t)argv[8]);
    } else if (strcmp(digoleCommand, "setRBGColor") == 0) {
        setRBGColor((uint8_t)atoi(argv[2]), (uint8_t)atoi(argv[3]), (uint8_t)atoi(argv[4]));
    } else if (strcmp(digoleCommand, "directByte") == 0) {
        writebyte((uint8_t)atoi(argv[2]));
    } else if (strcmp(digoleCommand, "myimage") == 0) {
        drawBitmap256K(0, 0, 160, 128, &imageData,0);
    }
    printf("\n");
	return 0;
}

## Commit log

2017-05-16 working picture to Digole display via re-compiled C driver
2017-06-14 added new settings, email command and STL files for the enclosure
    [DisplayBack.stl, DisplayBox-Back.stl, DisplayBox-Front.stl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]
2017-06-29 final updates for running the device
